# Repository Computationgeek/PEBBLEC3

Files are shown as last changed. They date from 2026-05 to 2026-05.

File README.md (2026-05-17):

# 🍊 FruitWorks PebbleC3

> **Built by makers, for makers.**

PebbleC3 Board

**PebbleC3** is a compact, open-source ESP32-C3 development board designed by [FruitWorks Electronics](https://github.com/fruitworkselectronics). Built as a portfolio and KiCad skill project, it packs native USB, Qwiic/STEMMA QT connectivity, and castellated edges into a small, orange form factor.

---

## ✨ Features

- **ESP32-C3-WROOM-02** — RISC-V single-core @ 160MHz, 4MB Flash, 400KB SRAM, Wi-Fi + BLE 5.0
- **Native USB** — Direct USB-C to ESP32-C3 USB (no CH340 or CP2102), supports CDC/JTAG
- **AP2112K-3.3 LDO** — 600mA, ultra-low dropout (350mV), SOT-23-5
- **Qwiic / STEMMA QT** — JST-SH 4-pin connector for plug-and-play I2C ecosystem
- **Castellated edges** — 8-pin castellated pads on each side, 2.54mm pitch, solderable directly to a carrier board
- **User LED + Power LED** — GPIO-driven user LED (IO3) and always-on power indicator
- **Boot + Reset buttons** — Standard tactile switches for programming and reset
- **Test points** — VOUT and GND test pads for bench probing
- **Open Source Hardware** — Full KiCad project, schematics, and Gerbers available

---

## 📐 Specifications

| Parameter | Value |
|---|---|
| MCU | ESP32-C3-WROOM-02 |
| Clock Speed | 160 MHz |
| Flash | 4MB |
| SRAM | 400KB |
| Connectivity | Wi-Fi 802.11 b/g/n + BLE 5.0 |
| USB | USB-C, Native USB 2.0 (CDC + JTAG) |
| Operating Voltage | 3.3V |
| Input Voltage (VIN) | 3.8V – 6V |
| Input Voltage (USB) | 5V |
| LDO Output Current | 600mA max |
| I2C | IO8 (SDA), IO10 (SCL) |
| PCB Layers | 2 |
| PCB Dimensions | ~52 x 36mm |
| PCB Color | Ember Orange |
| Finish | ENIG |

---

## 📌 Pinout

### Left Edge (J4)

| Pin | Signal | Notes |
|---|---|---|
| 1 | GND | Ground |
| 2 | 3V3 | 3.3V regulated output |
| 3 | IO4 | GPIO / ADC |
| 4 | IO5 | GPIO / ADC |
| 5 | IO6 | GPIO |
| 6 | IO7 | GPIO |
| 7 | IO8/SDA | GPIO / I2C Data |
| 8 | BOOT | GPIO9, Boot button net |

### Right Edge (J3)

| Pin | Signal | Notes |
|---|---|---|
| 1 | VIN | Raw voltage input (3.8–6V) |
| 2 | GND | Ground |
| 3 | IO0 | GPIO / ADC |
| 4 | IO1 | GPIO / ADC |
| 5 | IO2 | GPIO / ADC, strapping pin |
| 6 | IO10/SCL | GPIO / I2C Clock |
| 7 | RXD | UART RX (IO20) |
| 8 | TXD | UART TX (IO21) |

### Qwiic / STEMMA QT (J2)

| Pin | Signal |
|---|---|
| 1 | GND |
| 2 | 3.3V |
| 3 | SDA (IO8) |
| 4 | SCL (IO10) |

---

## 🧩 Bill of Materials

| Reference | Qty | Value | Footprint | Datasheet |
|---|---|---|---|---|
| C1, C2 | 2 | 1µF | C_0805_2012Metric | — |
| C3 | 1 | 100nF | C_0201_0603Metric | — |
| C4 | 1 | 10µF | C_0805_2012Metric | — |
| D1 | 1 | User LED | LED_0805_2012Metric | — |
| D2 | 1 | Power LED | LED_0805_2012Metric | — |
| D4 | 1 | 1N5819 (SOD-123W) | Nexperia_CFP3_SOD-123W | [Datasheet](http://www.vishay.com/docs/88525/1n5817.pdf) |
| J1 | 1 | USB-C 16P Receptacle | USB_C_Receptacle_GCT_USB4110 | [USB Spec](https://www.usb.org) |
| J2 | 1 | Qwiic / STEMMA QT | JST_SH_BM04B-SRSS-TB_1x04-1MP | — |
| J3 | 1 | Right Castellated Edge (8-pin) | PinHeader_1x08_P2.54mm | — |
| J4 | 1 | Left Castellated Edge (8-pin) | PinHeader_1x08_P2.54mm | — |
| R1, R2 | 2 | 5.1kΩ | R_0805_2012Metric | — |
| R3, R6 | 2 | 470Ω | R_0805_2012Metric | — |
| R4, R5 | 2 | 10kΩ | R_0805_2012Metric | — |
| SW1 | 1 | Reset Button | SW_SPST_TS-1088 | — |
| SW2 | 1 | Boot Button | SW_SPST_TS-1088 | — |
| TP1 | 1 | VOUT Test Point | TestPoint_Pad_D1.0mm | — |
| TP2 | 1 | GND Test Point | TestPoint_Pad_D1.0mm | — |
| U1 | 1 | ESP32-C3-WROOM-02 | ESP32-C3-WROOM-02 | [Datasheet](https://www.espressif.com/sites/default/files/documentation/esp32-c3-wroom-02_datasheet_en.pdf) |
| U2 | 1 | AP2112K-3.3 | SOT-23-5 | [Datasheet](https://www.diodes.com/assets/Datasheets/AP2112.pdf) |

---

## ⚡ Power

PebbleC3 can be powered two ways:

**Via USB-C** — 5V from USB → 1N5819 diode → AP2112K-3.3 LDO → 3.3V rail

**Via VIN pad** — 3.8V–6V on VIN castellation → 1N5819 → LDO → 3.3V rail

The 1N5819 Schottky diode provides OR-ing between USB and VIN — whichever is higher wins automatically. Forward drop is ~0.4V.

> ⚠️ Do not exceed 6V on VIN. AP2112K-3.3 absolute maximum input is 6V.

---

## 🔌 USB and Programming

PebbleC3 uses the ESP32-C3's **native USB** peripheral directly — no USB-to-UART bridge chip needed.

**To flash firmware:**

1. Hold **BOOT** button
2. Press and release **RESET**
3. Release **BOOT**
4. Flash using `esptool.py` or Arduino IDE

**Arduino IDE board selection:**
```
Board: ESP32C3 Dev Module
Upload Speed: 921600
USB CDC On Boot: Enabled
```
---

## 🏭 Manufacturing

Designed for JLCPCB 2-layer standard process.

| Setting | Value |
|---|---|
| Layers | 2 |
| Thickness | 1.6mm |
| Surface Finish | ENIG |
| Solder Mask | Orange |
| Silkscreen | White |
| Castellated Holes | Yes |
| Min Hole Size | 0.2mm |
| Min Clearance | 0.1mm |

> When ordering, select **"Castellated holes: Yes"** — without this JLCPCB will route through your castellation pads.

---

## 🔓 License

This project is **Open Source Hardware** licensed under the [CERN-OHL-P v2](https://ohwr.org/cern_ohl_p_v2.txt).

You are free to use, modify, and manufacture this design. Attribution to **FruitWorks Electronics** appreciated.

---

*Built by makers, for makers.*

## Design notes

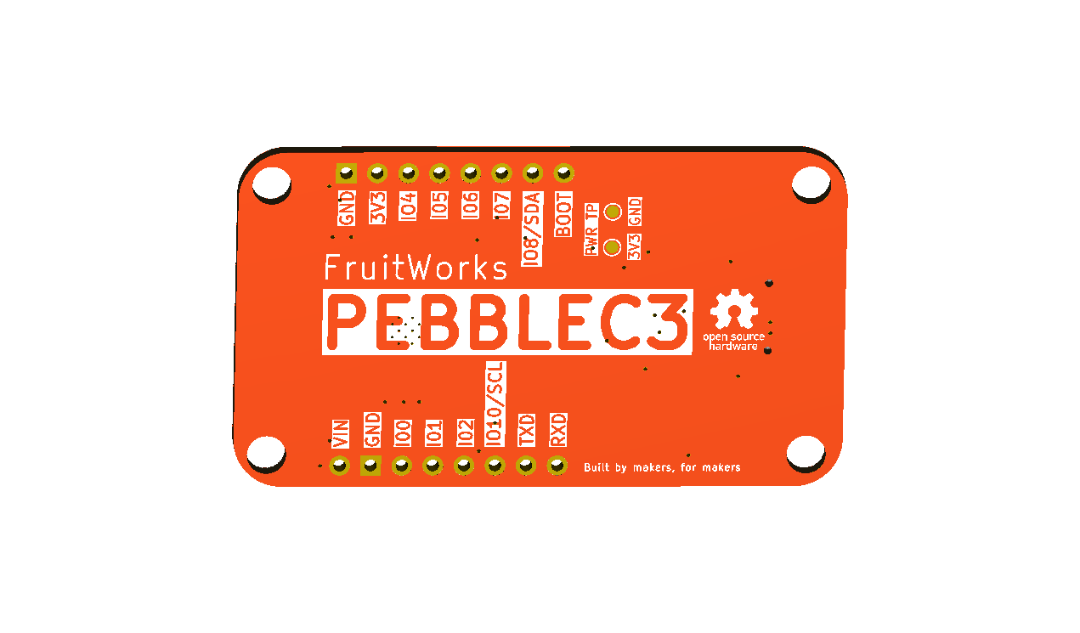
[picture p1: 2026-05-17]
Images/PEBBLEC3BV.png

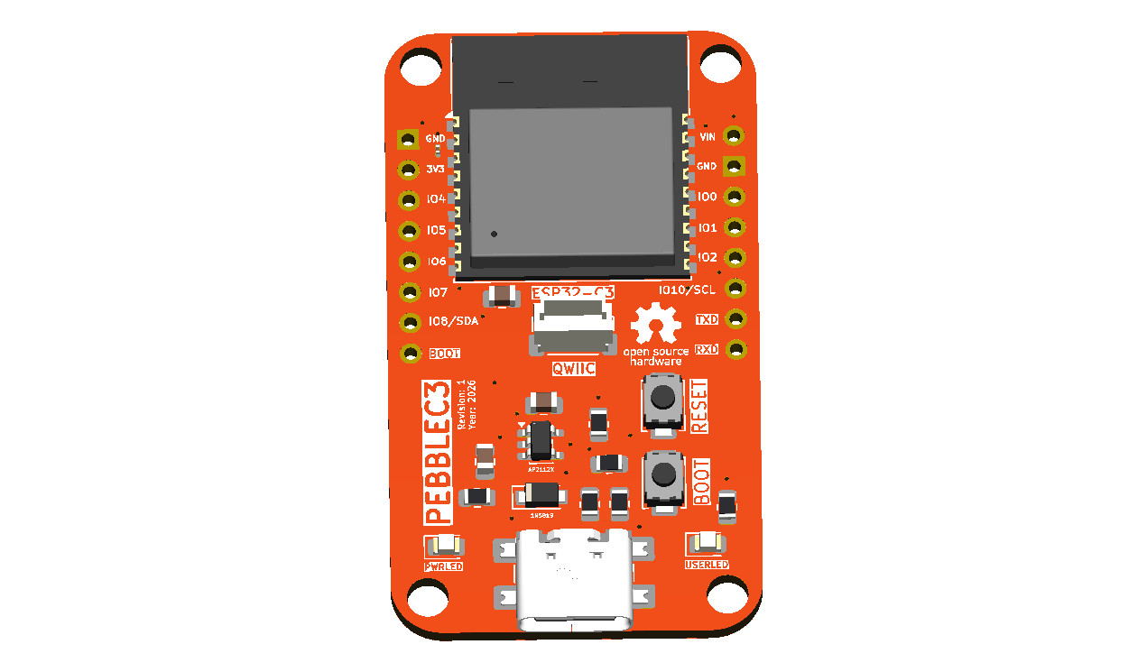
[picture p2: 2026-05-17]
Images/PEBBLEC3FV.png

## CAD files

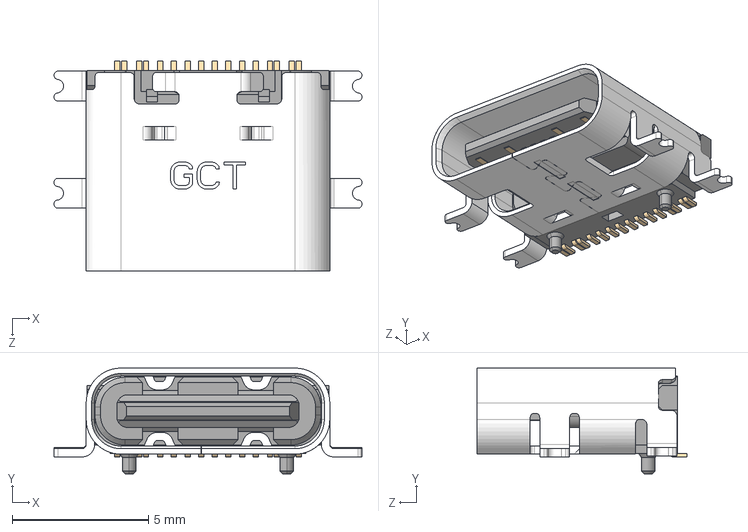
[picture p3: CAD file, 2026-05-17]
3D Model/LIB_USB4110-GF-A/USB4110-GF-A/3D/USB4110-GF-A.stp
11.3 x 3.89 x 7.70 mm

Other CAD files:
3D Model/LIB_USB4110-GF-A/USB4110-GF-A/Allegro/usb4110gfa.psm
3D Model/LIB_USB4110-GF-A/USB4110-GF-A/DEHDL/usb4110_gf_a/chips/chips.prt

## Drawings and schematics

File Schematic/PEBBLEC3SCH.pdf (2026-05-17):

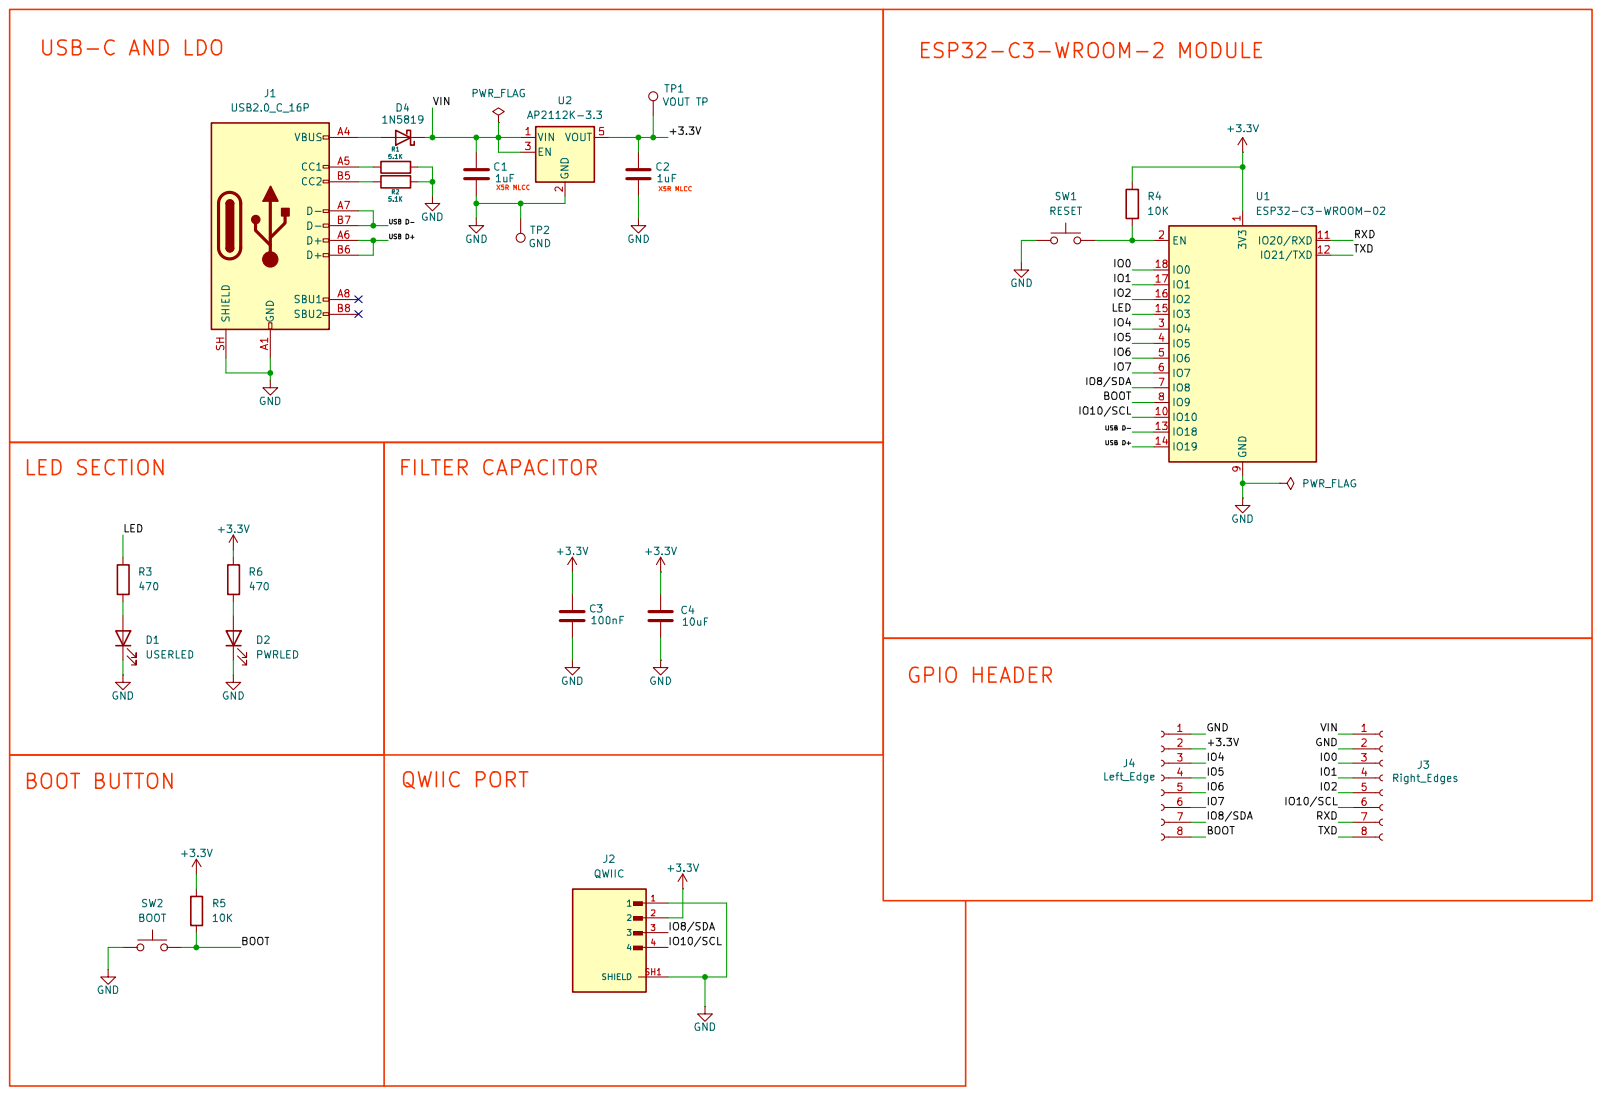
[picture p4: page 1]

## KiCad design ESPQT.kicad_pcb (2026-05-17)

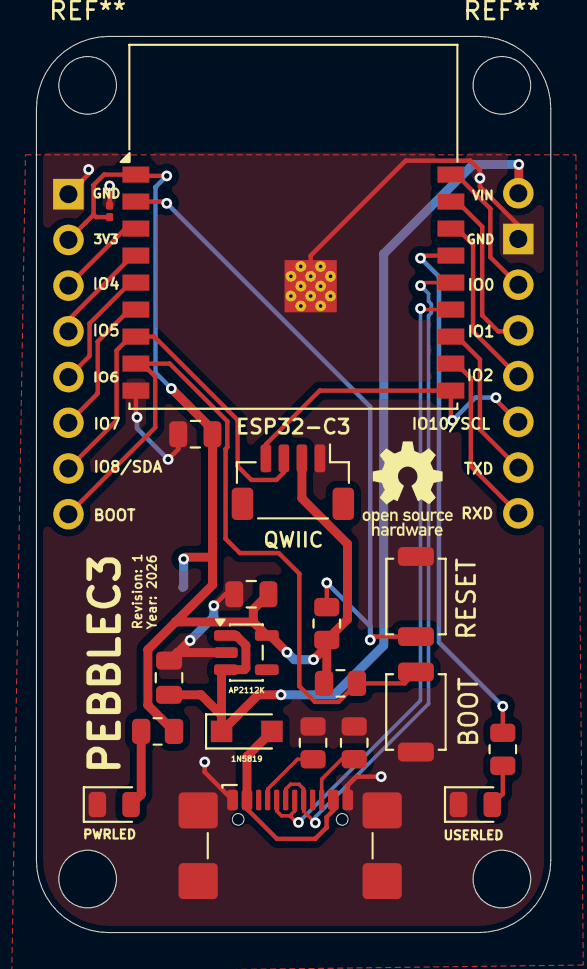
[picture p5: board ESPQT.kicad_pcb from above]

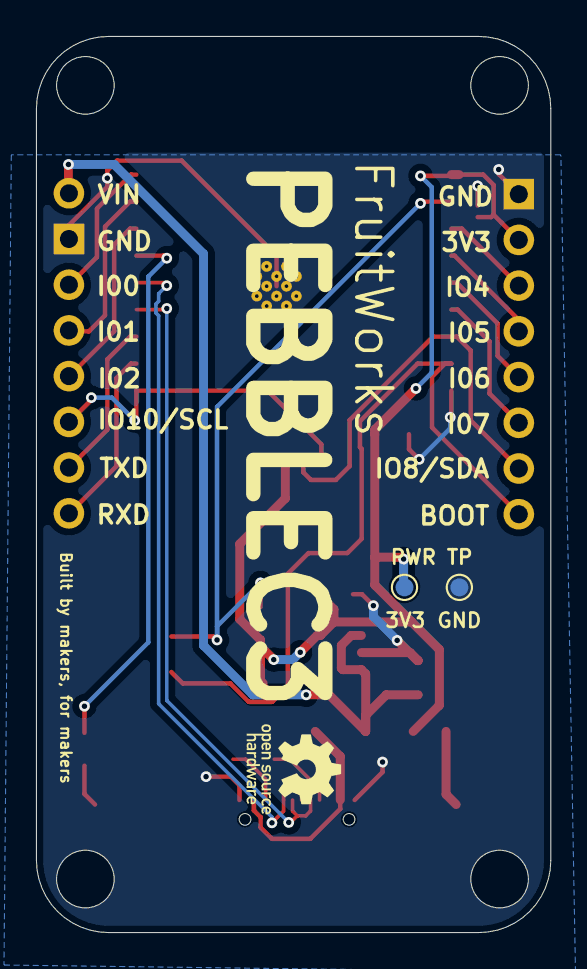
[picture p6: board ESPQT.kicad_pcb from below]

Board: 2 copper layers, 28.6 x 49.8 mm, 23 parts (2 on the bottom side), 24 nets.

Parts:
C1, C2: 1uF; C_0805_2012Metric
C3: 100nF; C_0201_0603Metric
C4: 10uF; C_0805_2012Metric
D1: USERLED; LED_0805_2012Metric
D2: PWRLED; LED_0805_2012Metric
D4: 1N5819; Nexperia_CFP3_SOD-123W
J1: USB2.0_C_16P; USB_C_Receptacle_GCT_USB4110
J2: QWIIC; JST_SH_BM04B-SRSS-TB_1x04-1MP_P1.00mm_Vertical
J3: Right_Edges; PinHeader_1x08_P2.54mm_Vertical_Mod
J4: Left_Edge; PinHeader_1x08_P2.54mm_Vertical_Mod
R1, R2: 5.1K; R_0805_2012Metric
R3, R6: 470; R_0805_2012Metric
R4, R5: 10K; R_0805_2012Metric
SW1: RESET; SW_SPST_TS-1088-xR020
SW2: BOOT; SW_SPST_TS-1088-xR020
TP1: 3V3; TestPoint_Pad_D1.0mm
TP2: GND; TestPoint_Pad_D1.0mm
U1: ESP32-C3; ESP32-C3-WROOM-02
U2: AP2112K; SOT-23-5

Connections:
+3.3V: C2.1, C3.1, C4.1, J2.2, J4.2, R4.1, R5.1, R6.1, TP1.1 (1_1), U1.1 (3V3), U2.5 (VOUT)
/BOOT: J4.8, R5.2, SW2.2, U1.8 (IO9)
/IO0: J3.3, U1.18 (IO0)
/IO1: J3.4, U1.17 (IO1)
/IO2: J3.5, U1.16 (IO2)
/IO4: J4.3, U1.3 (IO4)
/IO5: J4.4, U1.4 (IO5)
/IO6: J4.5, U1.5 (IO6)
/IO7: J4.6, U1.6 (IO7)
/IO8/SDA: J2.3, J4.7, U1.7 (IO8)
/IO10/SCL: J2.4, J3.6, U1.10 (IO10)
/LED: R3.1, U1.15 (IO3)
/RXD: J3.8, U1.11 (IO20/RXD)
/TXD: J3.7, U1.12 (IO21/TXD)
/USB D+: J1.A6 (D+), J1.B6 (D+), U1.14 (IO19)
/USB D-: J1.A7 (D-), J1.B7 (D-), U1.13 (IO18)
/VIN: C1.1, D4.1 (K), J3.1, U2.1 (VIN), U2.3 (EN)
GND: C1.2, C2.2, C3.2, C4.2, D1.1 (K), D2.1 (K), J1.A1 (GND), J1.A12 (GND), J1.B1 (GND), J1.B12 (GND), J1.SH (SHIELD), J2.1, J3.2, J4.1, R1.2, R2.2, SW1.1, SW2.1, TP2.1 (1_1), U1.9 (GND), U1.19 (GND), U2.2 (GND)
unnamed: D1.2 (A), R3.2
unnamed: D2.2 (A), R6.2
unnamed: D4.2 (A), J1.A4 (VBUS), J1.A9 (VBUS), J1.B4 (VBUS), J1.B9 (VBUS)
unnamed: J1.A5 (CC1), R1.1
unnamed: J1.B5 (CC2), R2.1
unnamed: R4.2, SW1.2, U1.2 (EN)
